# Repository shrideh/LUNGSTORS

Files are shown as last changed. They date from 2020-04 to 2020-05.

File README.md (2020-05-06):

**Full project presentation available at: https://protors.co/lungstors/**

# LUNGSTORS
**Blower based Open Source Medical Ventilator**

<p align="center">
  
  
</p>

## License
Copyright (C) 2020 PROTORS  <info@protors.co>

Licensed under CERN-OHL-P version 2

You may redistribute and modify this documentation and make products
using it under the terms of the [CERN-OHL-P v2](https://ohwr.org/project/cernohl/wikis/Documents/CERN-OHL-version-2).
This documentation is distributed WITHOUT ANY EXPRESS OR IMPLIED
WARRANTY, INCLUDING OF MERCHANTABILITY, SATISFACTORY QUALITY
AND FITNESS FOR A PARTICULAR PURPOSE. Please see the CERN-OHL-P v2
for applicable conditions.

For more information view [LICENSE.txt](./LICENSE.txt) file.

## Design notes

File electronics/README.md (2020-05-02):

**Full project presentation available at: https://protors.co/lungstors/**
# PROCESS BOARD
The *KiCad* projects of the printed circuit boards for process control are available in subfolders.

## PROCESS BOARD SMD
In folder `PROCESS_BOARD_SMD` a surface-mount device (SMD) version is available.
<p align="center">
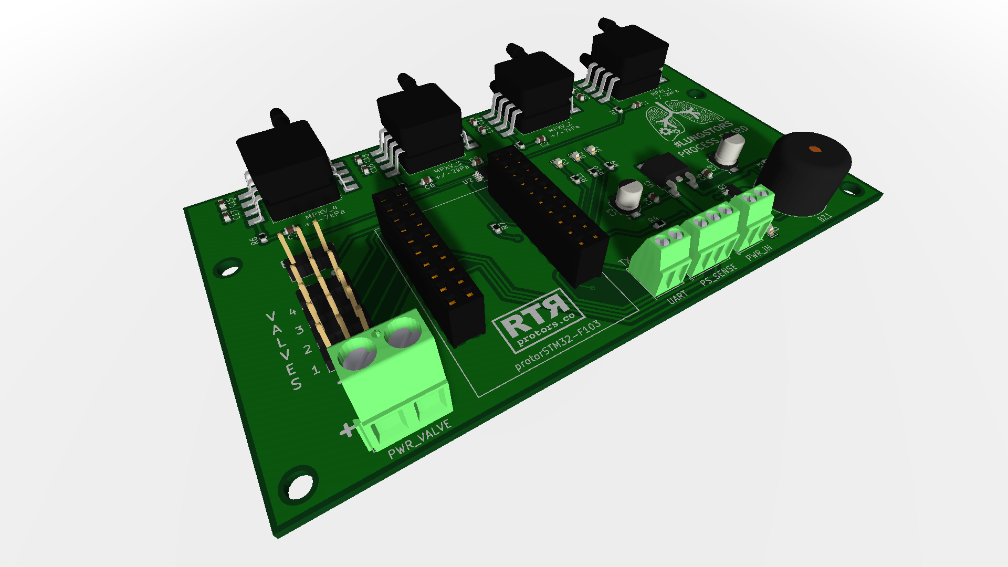
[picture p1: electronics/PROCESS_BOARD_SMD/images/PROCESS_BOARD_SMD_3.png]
  
</p>

## PROCESS BOARD TH
In folder `PROCESS_BOARD_TH` a through-hole (TH) version is available.

<p align="center">
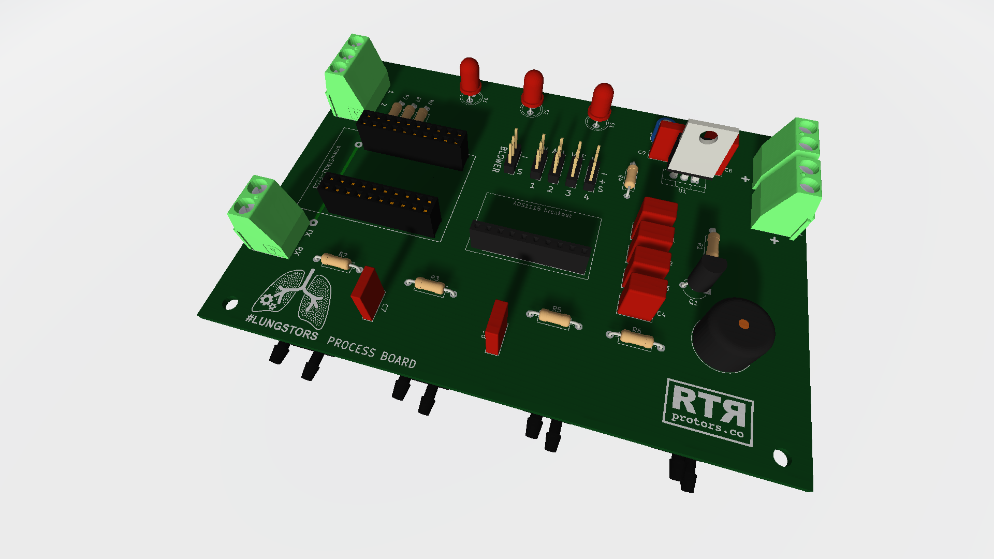
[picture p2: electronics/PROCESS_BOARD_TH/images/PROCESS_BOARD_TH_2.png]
  
</p>

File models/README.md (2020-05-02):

**Full project presentation available at: https://protors.co/lungstors/**
# 3D Models

All of technical documentation given here is made using FreeCAD. Using the FreeCAD native file format, anyone can see how we designed all the models and can easily edit and adapt the design to personal needs. FreeCAD is an open-source parametric 3D modeler made primarily to design real-life objects of any size.

## BLOWER
In folder `compressor_assembly` 3D models of our blower are available.
<p align="center">
  
</p>

## SERVO VALVE
In folder `servo_valve_assembly` 3D models of our servo valve are available.
<p align="center">
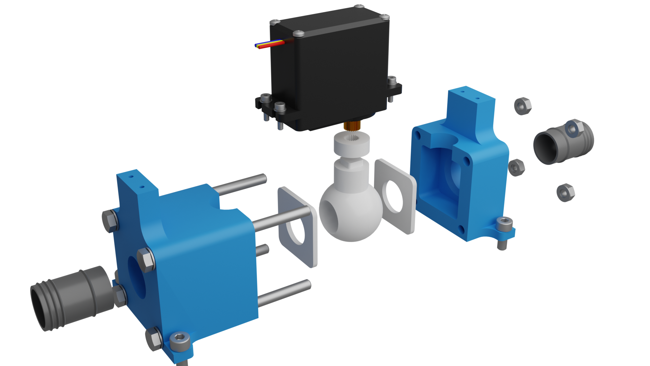
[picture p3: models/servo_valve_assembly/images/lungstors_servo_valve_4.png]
  
</p>

## FLOW METER
In folder `flowmeter_assembly` 3D models of our flow meter are available.
<p align="center">
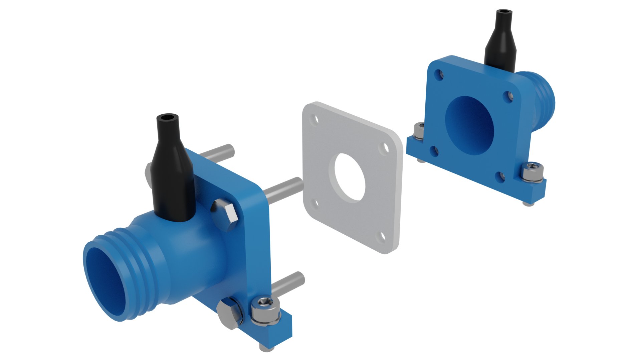
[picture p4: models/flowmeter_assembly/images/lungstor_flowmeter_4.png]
  
</p>

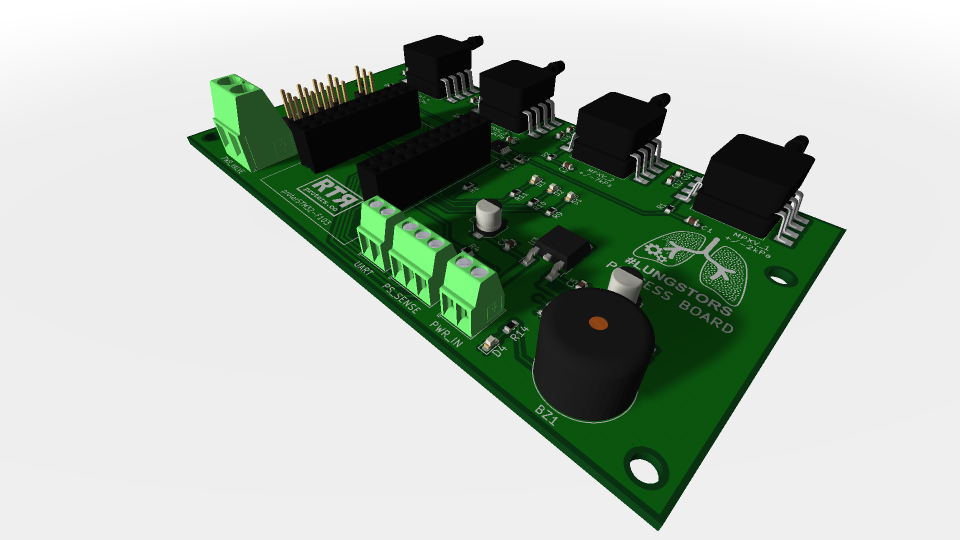
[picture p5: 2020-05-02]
electronics/PROCESS_BOARD_SMD/images/PROCESS_BOARD_SMD_4.png

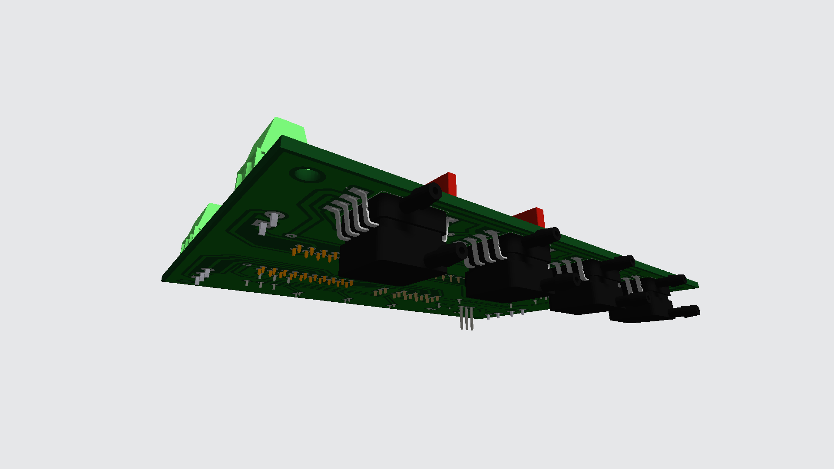
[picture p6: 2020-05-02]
electronics/PROCESS_BOARD_TH/images/PROCESS_BOARD_TH_4.png

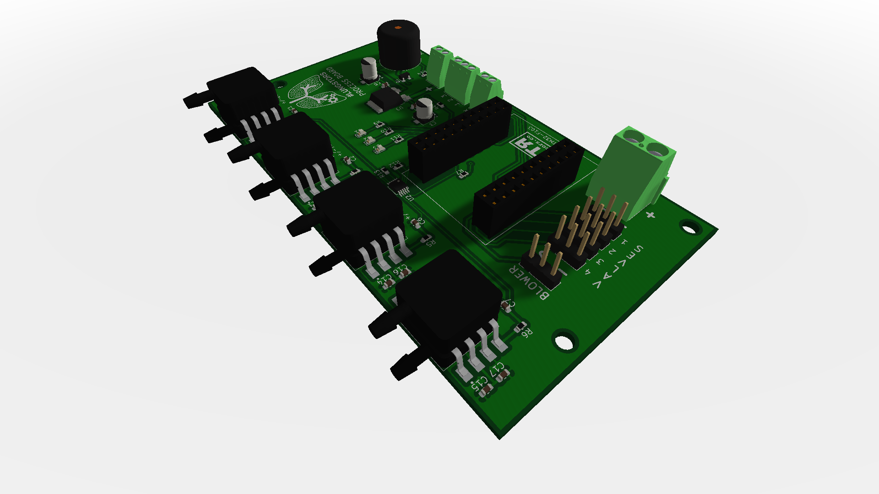
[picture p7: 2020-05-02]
electronics/PROCESS_BOARD_SMD/images/PROCESS_BOARD_SMD_1.png

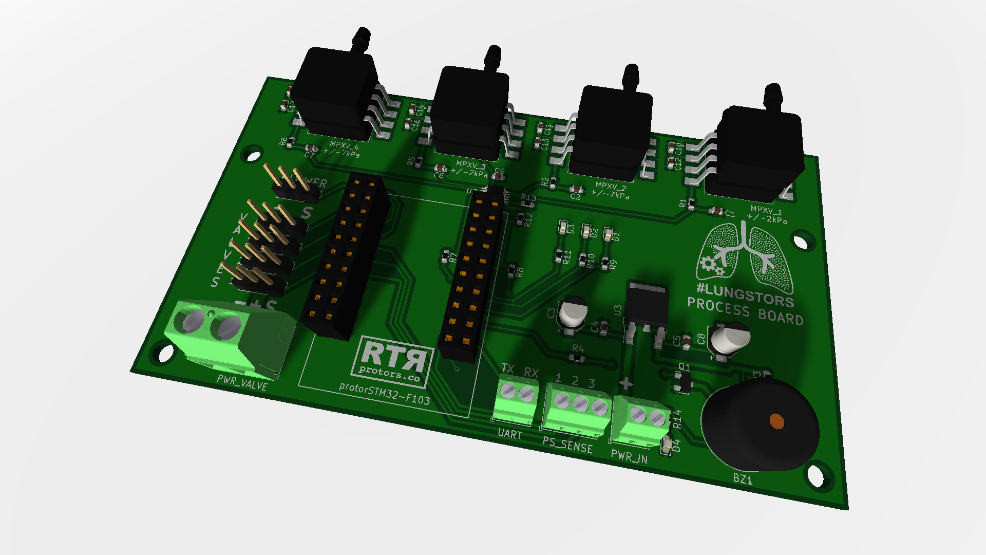
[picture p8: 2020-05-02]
electronics/PROCESS_BOARD_SMD/images/PROCESS_BOARD_SMD_2.png

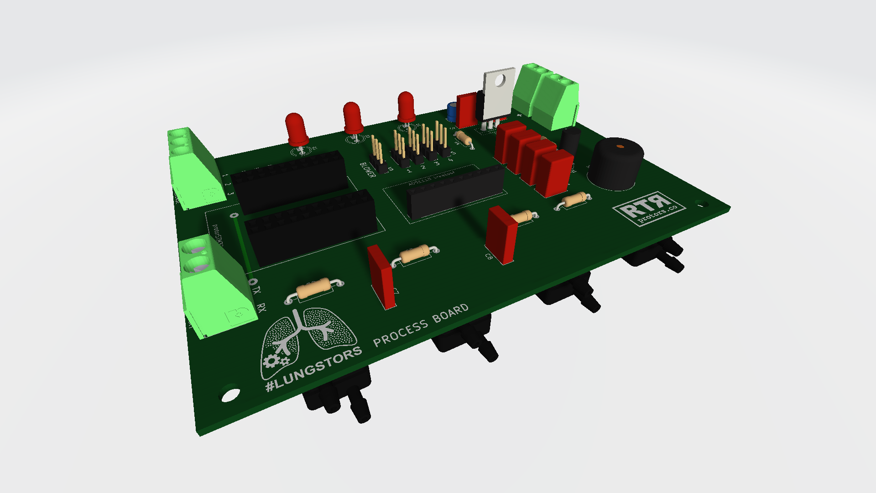
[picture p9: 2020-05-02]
electronics/PROCESS_BOARD_TH/images/PROCESS_BOARD_TH_1.png

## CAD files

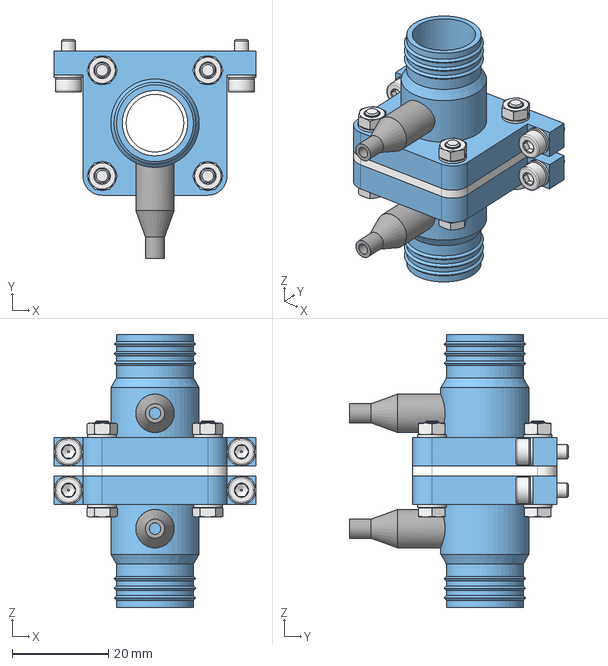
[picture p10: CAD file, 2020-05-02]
models/flowmeter_assembly/flowmeter_assembly.step
42.0 x 45.7 x 56.8 mm

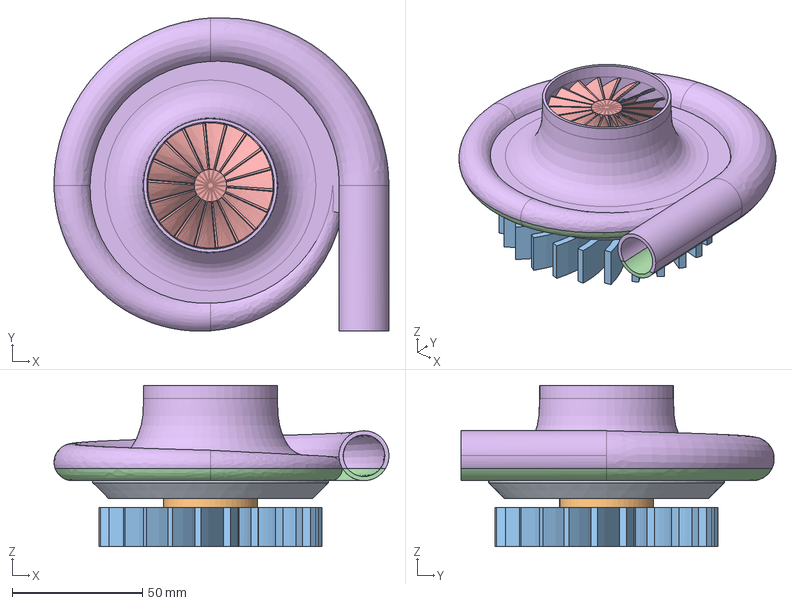
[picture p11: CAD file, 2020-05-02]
models/compressor_assembly/compressor_assembly.FCStd
128.7 x 120.4 x 61.9 mm
base_001
motor_base_001
radiator_001
volute_bottom_001
impeler_001
volute_001
bldc_motor_001

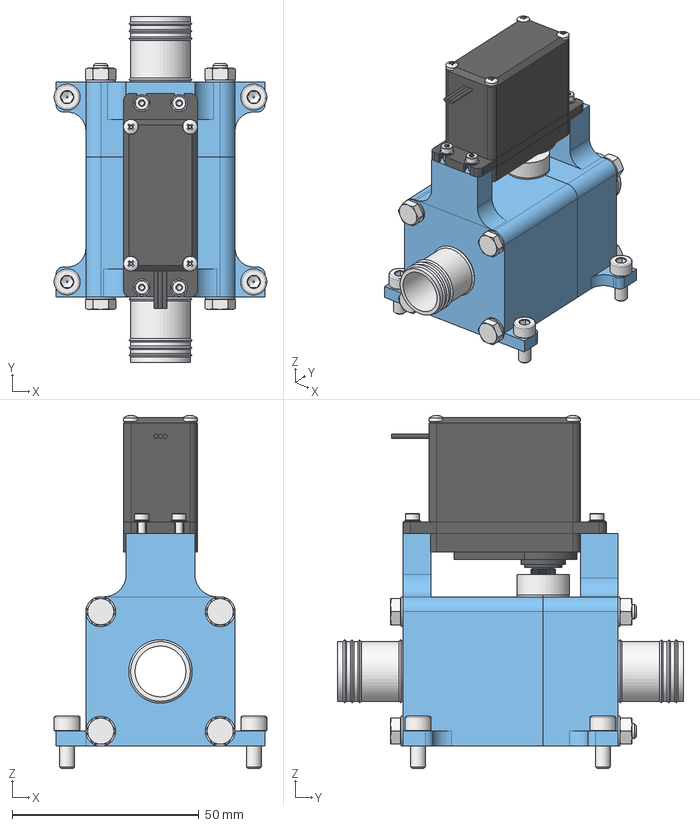
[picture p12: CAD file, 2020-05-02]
models/servo_valve_assembly/servo_valve_assembly.FCStd
57.0 x 92.8 x 94.6 mm
ball_001
ball_002
coupling_001
housing_left_001
housing_right_001
servo_001
gasket_001
gasket_002
hose_connector_001
hose_connector_002
M4x10-Screw
M4x10-Screw003
M4x10-Screw001
M4x10-Screw002
M2x5-Screw
M2x5-Screw004
M2x5-Screw005
M2x5-Screw006
M4-Washer
M4-Washer001
M4-Washer002
M4-Washer003
M4-Washer004
M4-Washer005
M4-Washer006
M4-Washer007
M4-Nut
M4-Nut001
M4-Nut002
M4-Nut003
M4x63-Screw
M4x63-Screw001
M4x63-Screw003
M4x63-Screw002
M2-Washer
M2-Washer001
M2-Washer002
M2-Washer003
M2x8-Screw
M2x8-Screw001
M2x8-Screw002
M2x8-Screw003

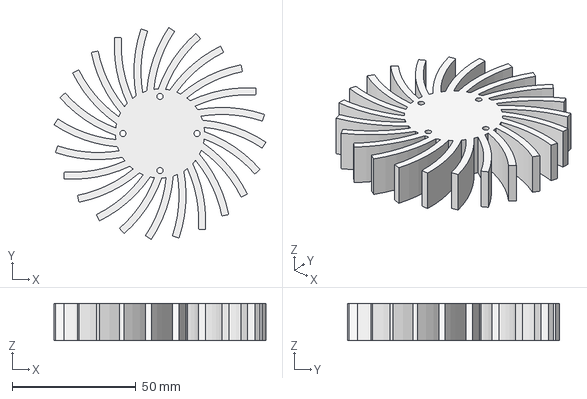
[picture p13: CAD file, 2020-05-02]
models/compressor_assembly/radiator.step
85.7 x 85.7 x 15.0 mm

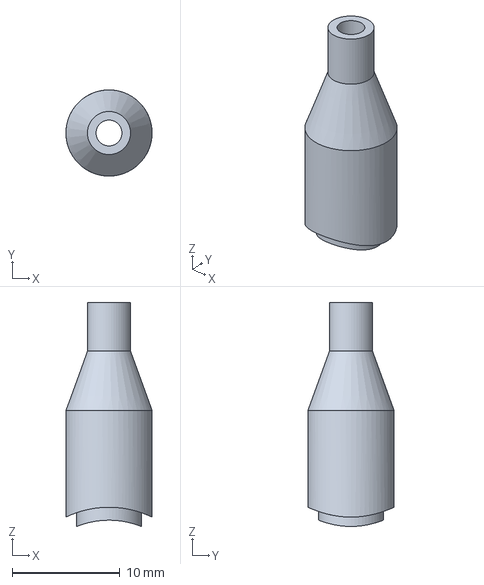
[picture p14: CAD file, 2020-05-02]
models/flowmeter_assembly/pressure_connector.step
8.00 x 8.00 x 20.8 mm

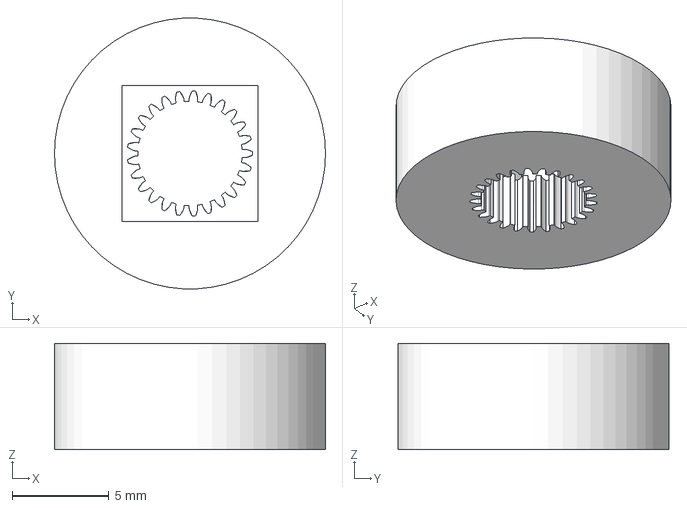
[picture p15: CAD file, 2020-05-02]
models/servo_valve_assembly/coupling.step
14.0 x 14.0 x 5.50 mm

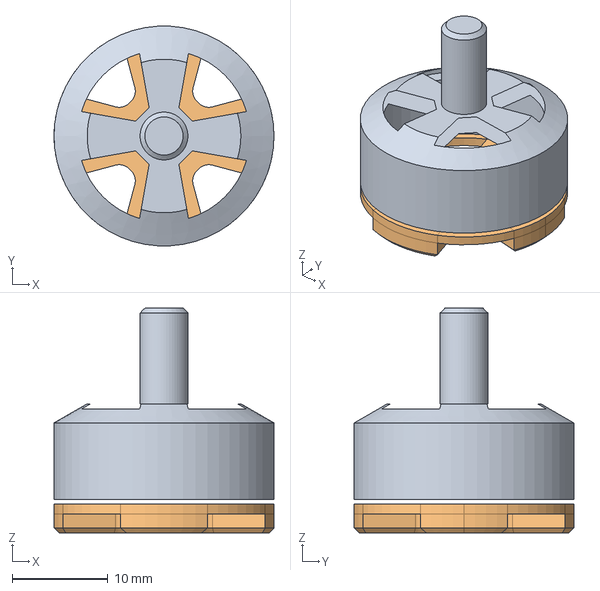
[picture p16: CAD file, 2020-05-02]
models/compressor_assembly/bldc_motor.step
23.0 x 23.0 x 23.5 mm

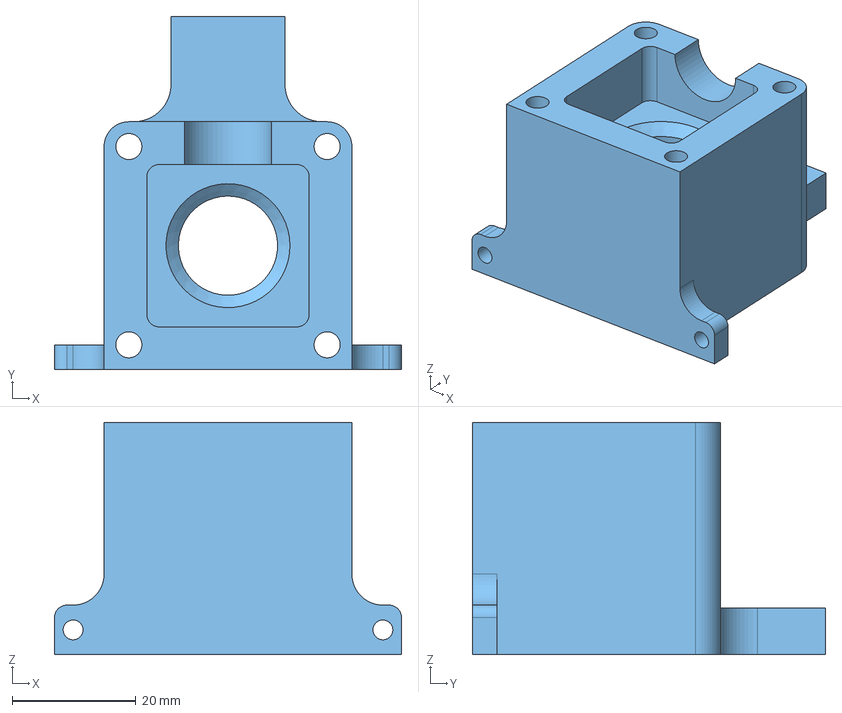
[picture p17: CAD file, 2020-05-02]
models/servo_valve_assembly/housing_right.step
56.0 x 57.0 x 37.5 mm

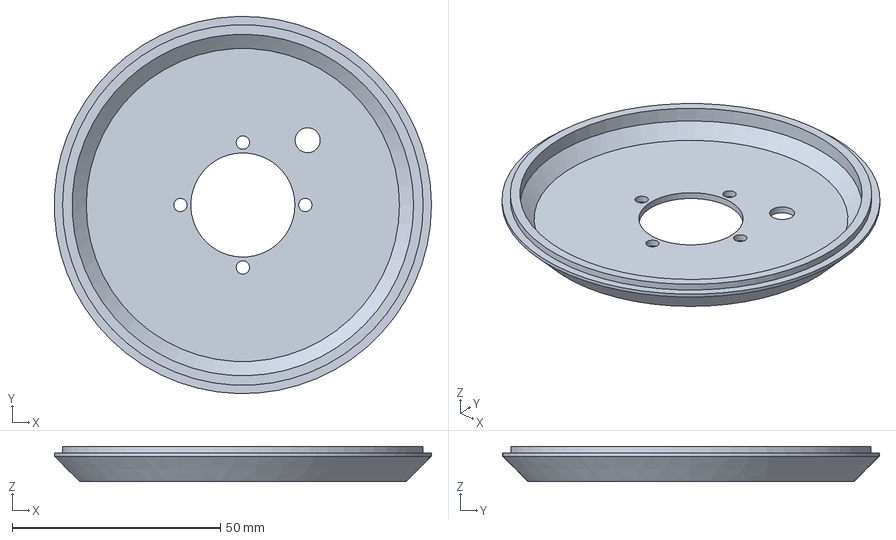
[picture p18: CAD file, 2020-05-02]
models/compressor_assembly/base.step
90.5 x 90.6 x 8.50 mm

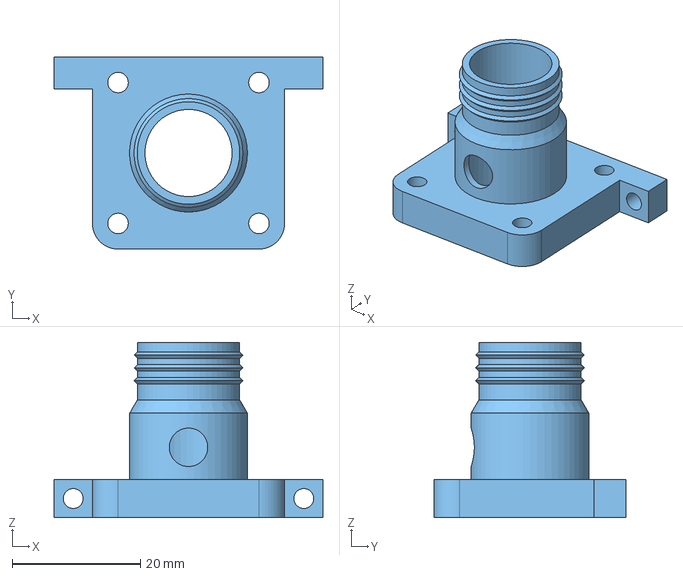
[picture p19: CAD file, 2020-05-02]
models/flowmeter_assembly/housing.step
42.0 x 30.0 x 27.4 mm

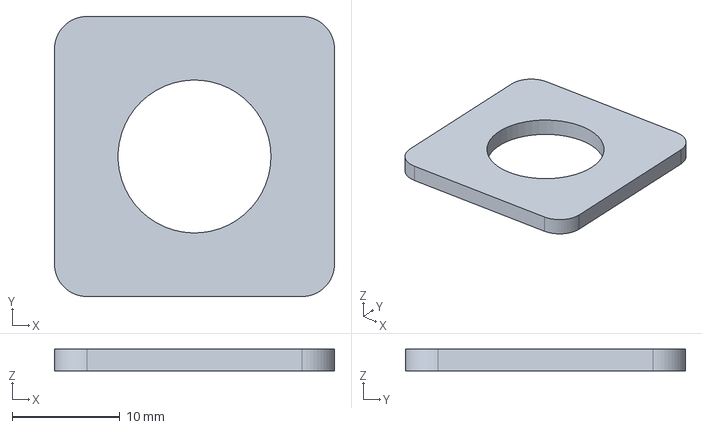
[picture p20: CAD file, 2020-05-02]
models/servo_valve_assembly/gasket.step
26.0 x 26.0 x 2.00 mm

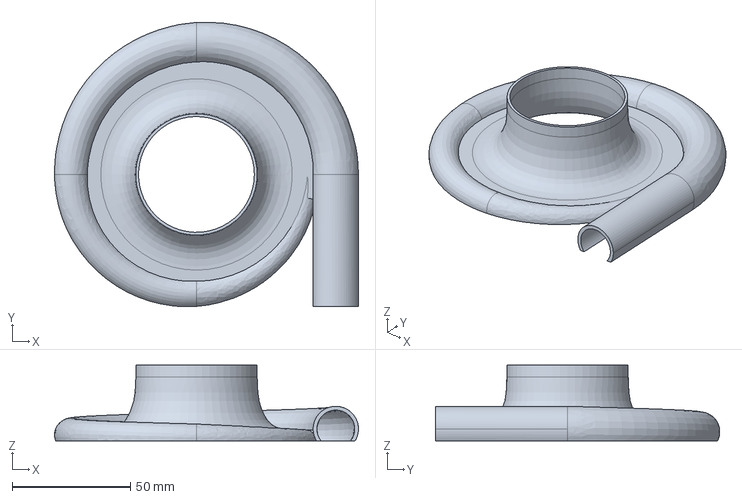
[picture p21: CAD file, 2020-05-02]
models/compressor_assembly/volute_top.step
128.7 x 120.4 x 32.0 mm

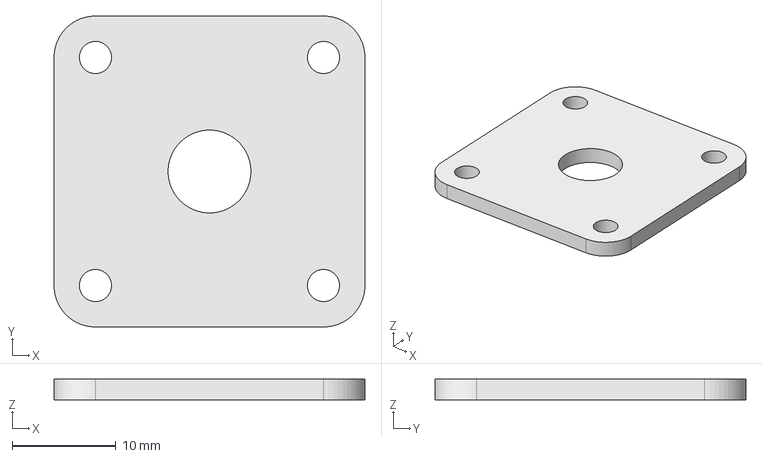
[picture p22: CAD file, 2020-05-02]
models/flowmeter_assembly/orifice.step
30.0 x 30.0 x 2.00 mm

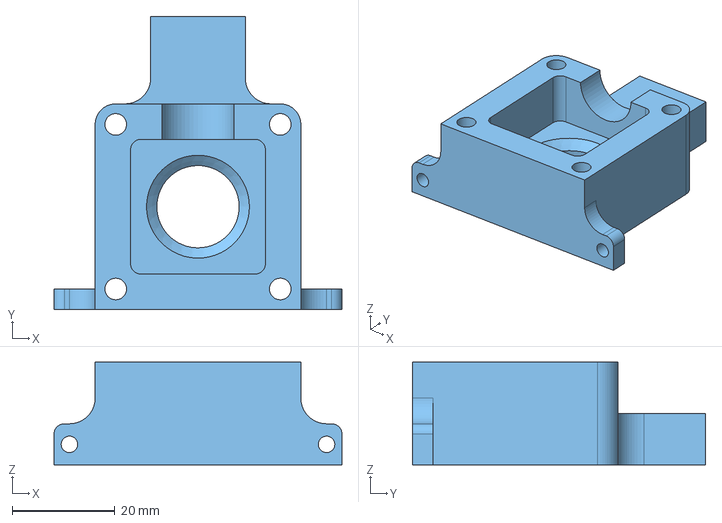
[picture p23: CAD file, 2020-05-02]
models/servo_valve_assembly/housing_left.step
56.0 x 57.0 x 20.0 mm

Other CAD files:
models/compressor_assembly/impeler.stl
models/servo_valve_assembly/hose_connector.step
models/compressor_assembly/volute_bottom.step
models/servo_valve_assembly/ball.step
models/compressor_assembly/base.FCStd
models/compressor_assembly/base.stl
models/compressor_assembly/bldc_motor.FCStd
models/compressor_assembly/bldc_motor.stl
models/compressor_assembly/motor_base.FCStd
models/compressor_assembly/motor_base.step
models/compressor_assembly/motor_base.stl
models/compressor_assembly/radiator.FCStd
models/compressor_assembly/radiator.stl
models/compressor_assembly/volute_bottom.FCStd
models/compressor_assembly/volute_bottom.stl
models/compressor_assembly/volute_top.FCStd
models/compressor_assembly/volute_top.stl
models/flowmeter_assembly/flowmeter_assembly.FCStd
models/flowmeter_assembly/flowmeter_assembly.stl
models/flowmeter_assembly/housing.FCStd
models/flowmeter_assembly/housing.stl
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

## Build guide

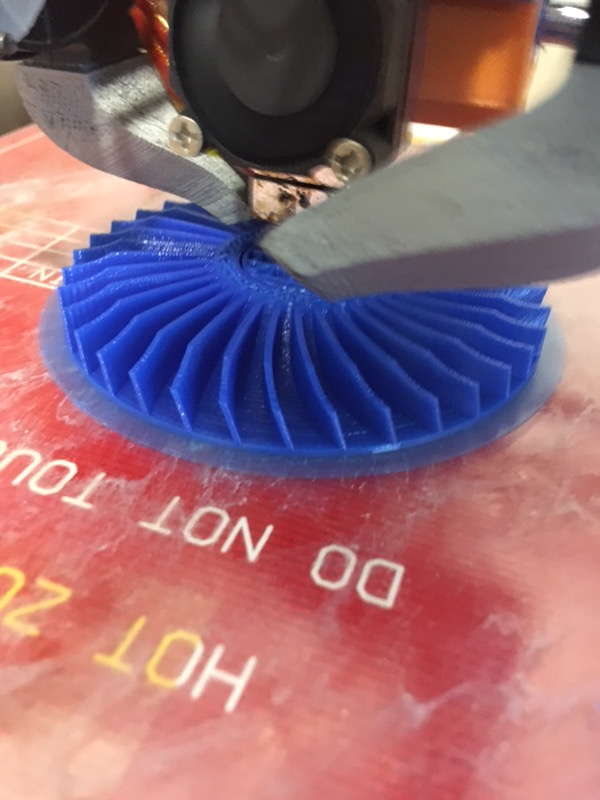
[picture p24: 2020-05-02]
models/compressor_assembly/images/lungstors_blower_2.JPG

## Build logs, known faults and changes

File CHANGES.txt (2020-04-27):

--------------------
LUNGSTORS
Blower based Open Source Mechanical Ventilator
--------------------

Release 1.0.0, 27.04.2020.

- Initial release

--------------------

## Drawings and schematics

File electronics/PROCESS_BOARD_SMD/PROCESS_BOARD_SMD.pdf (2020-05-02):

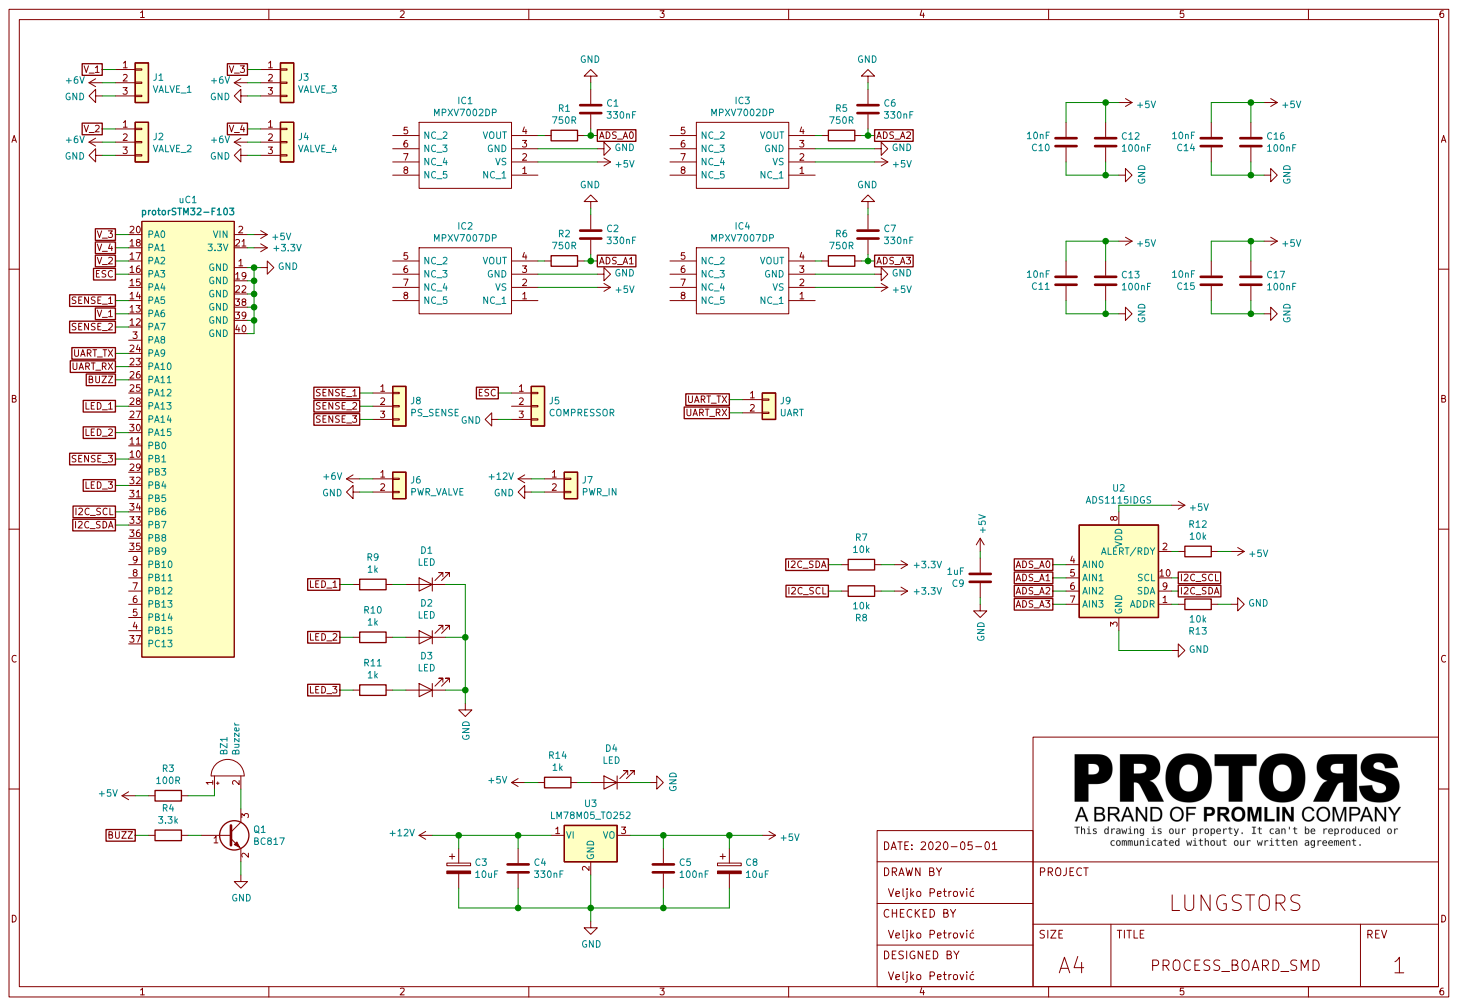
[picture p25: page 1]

2 BZ1 Buzzer NC_1 1 VS 2 GND 3 VOUT 4 NC_2 5 NC_3 6 NC_4 7 NC_5 8

DESIGNED BY CHECKED BY DRAWN BY
LUNGSTORS Veljko Petrovi

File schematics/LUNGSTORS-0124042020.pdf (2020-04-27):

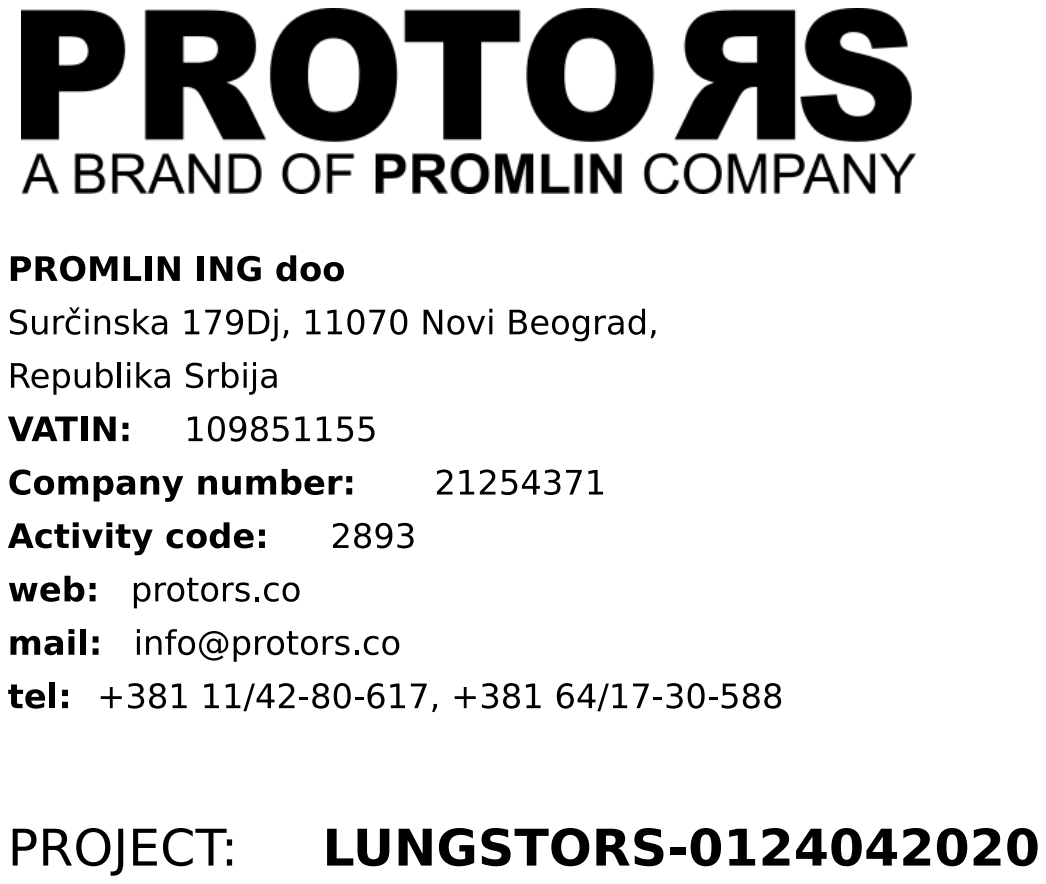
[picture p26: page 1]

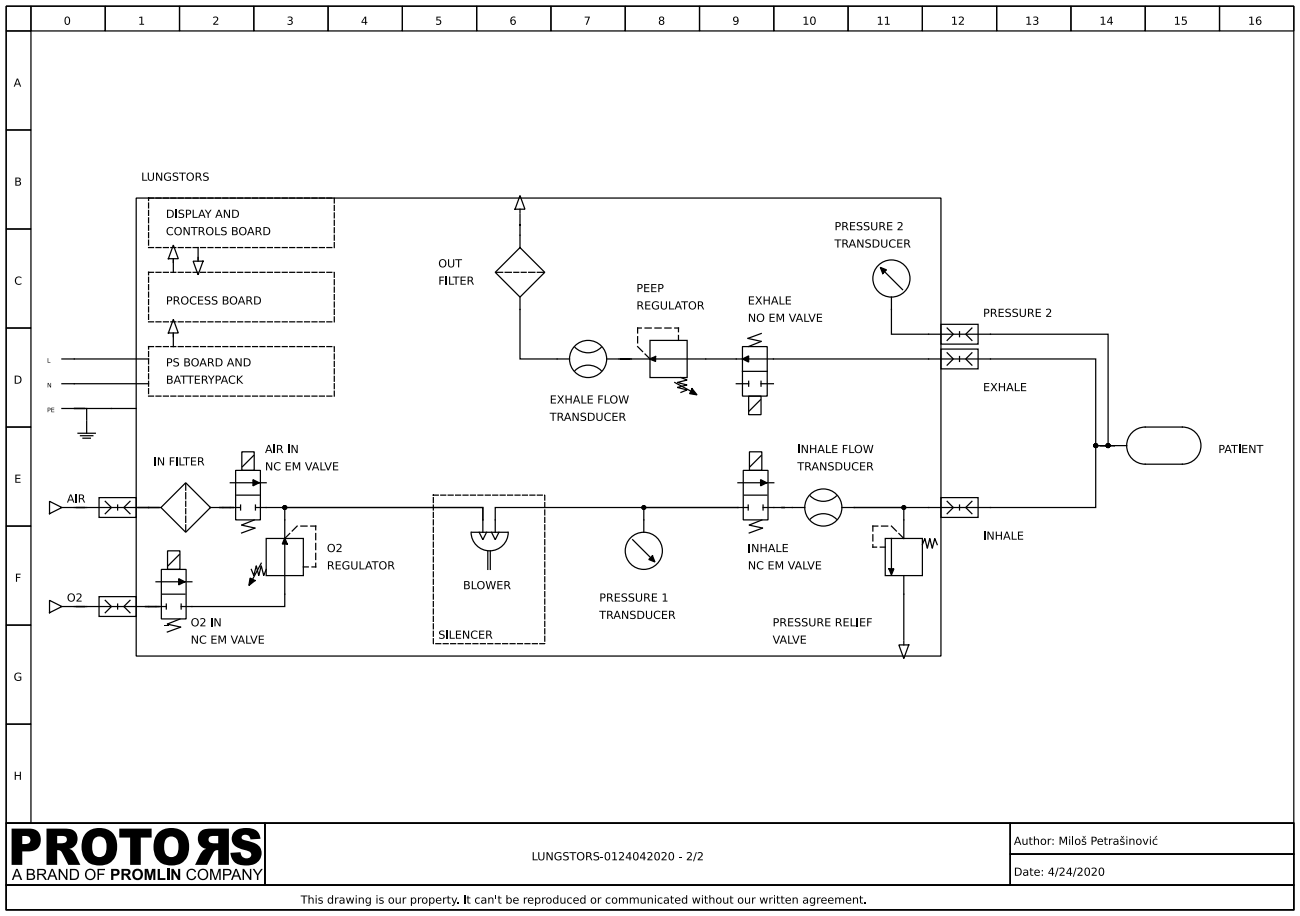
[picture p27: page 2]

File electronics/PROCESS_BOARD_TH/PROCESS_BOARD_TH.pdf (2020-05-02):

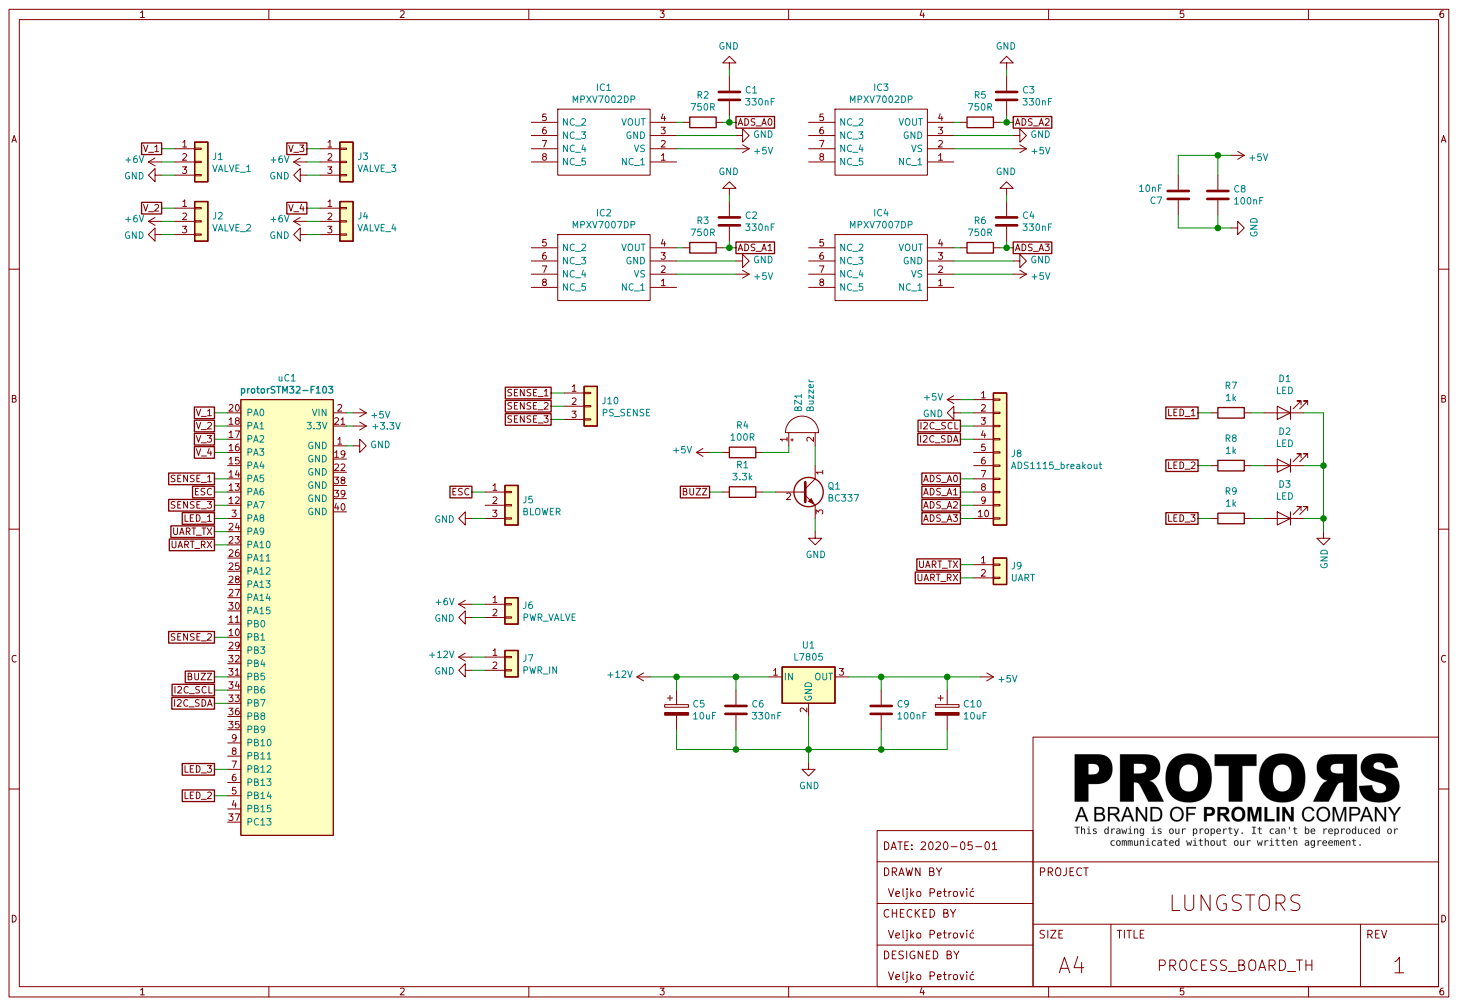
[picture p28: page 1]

DESIGNED BY CHECKED BY DRAWN BY | | LUNGSTORS Veljko Petrovi

PROCESS_BOARD_TH | 1 | D A4

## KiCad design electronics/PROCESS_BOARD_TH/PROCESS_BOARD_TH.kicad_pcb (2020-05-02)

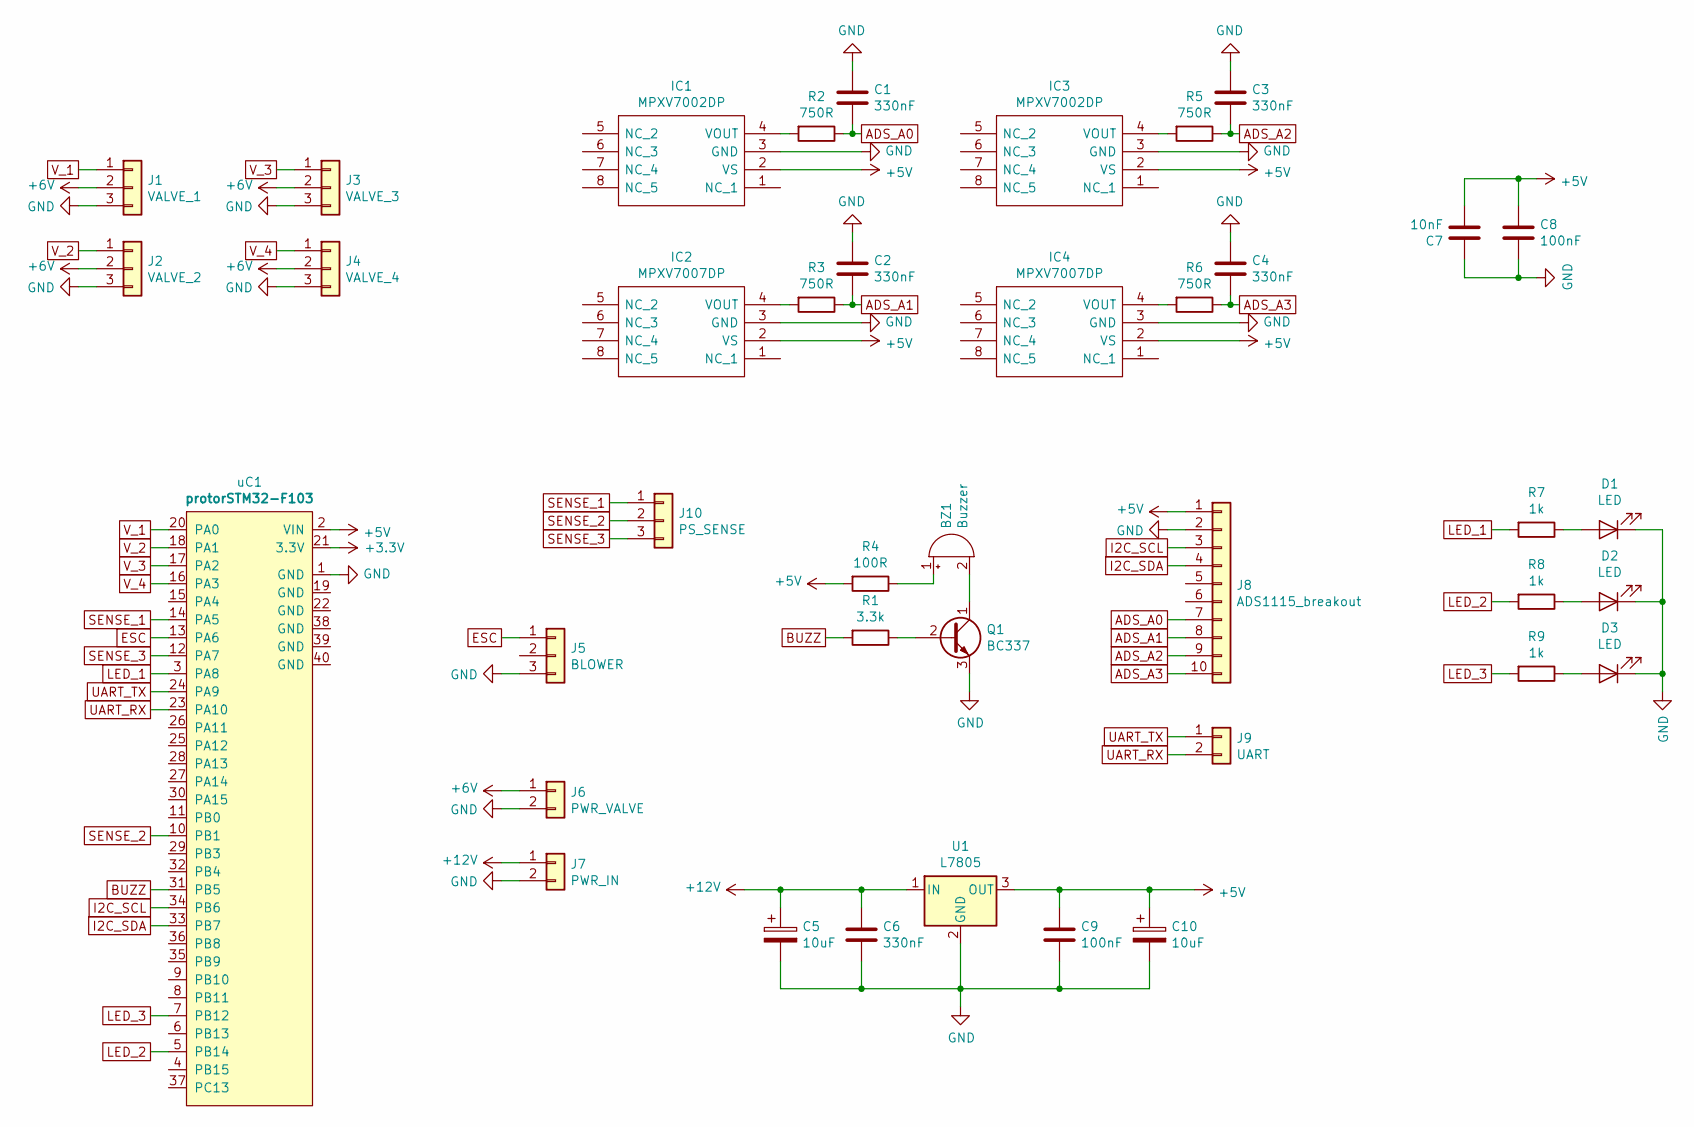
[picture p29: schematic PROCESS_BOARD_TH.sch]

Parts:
BZ1: Buzzer; Buzzer_12x9.5RM7.6
C1, C2, C3, C4, C6: 330nF; C_Rect_L7.0mm_W4.5mm_P5.00mm
C5, C10: 10uF; CP_Radial_D5.0mm_P2.50mm
C7: 10nF; C_Rect_L7.0mm_W2.0mm_P5.00mm
C8, C9: 100nF; C_Rect_L7.0mm_W2.5mm_P5.00mm
D1, D2, D3: LED; LED_D5.0mm
IC1, IC3: MPXV7002DP; MPXV7002DPT1
IC2, IC4: MPXV7007DP; MPXV7002DPT1
J1: VALVE_1; PinHeader_1x03_P2.54mm_Vertical
J2: VALVE_2; PinHeader_1x03_P2.54mm_Vertical
J3: VALVE_3; PinHeader_1x03_P2.54mm_Vertical
J4: VALVE_4; PinHeader_1x03_P2.54mm_Vertical
J5: BLOWER; PinHeader_1x03_P2.54mm_Vertical
J6: PWR_VALVE; TerminalBlock_bornier-2_P5.08mm
J7: PWR_IN; TerminalBlock_bornier-2_P5.08mm
J8: ADS1115_breakout; PinSocket_1x10_P2.54mm_Vertical
J9: UART; TerminalBlock_bornier-2_P5.08mm
J10: PS_SENSE; TerminalBlock_bornier-3_P5.08mm
Q1: BC337; TO-92L_Inline_Wide
R1: 3.3k; R_Axial_DIN0207_L6.3mm_D2.5mm_P10.16mm_Horizontal
R2, R3, R5, R6: 750R; R_Axial_DIN0207_L6.3mm_D2.5mm_P10.16mm_Horizontal
R4: 100R; R_Axial_DIN0207_L6.3mm_D2.5mm_P10.16mm_Horizontal
R7, R8, R9: 1k; R_Axial_DIN0207_L6.3mm_D2.5mm_P10.16mm_Horizontal
U1: L7805; TO-220-3_Vertical
uC1: protorSTM32-F103; protorSTM32-F103v1.1

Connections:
+5V: C7.2, C8.1, C9.1, C10.1, IC1.2 (VS), IC2.2 (VS), IC3.2 (VS), IC4.2 (VS), J8.1, R4.2, U1.3 (OUT), uC1.2 (VIN)
+6V: J1.2, J2.2, J3.2, J4.2, J6.1
+12V: C5.1, C6.1, J7.1, U1.1 (IN)
ADS_A0: C1.2, J8.7, R2.1
ADS_A1: C2.2, J8.8, R3.1
ADS_A2: C3.2, J8.9, R5.1
ADS_A3: C4.2, J8.10, R6.1
BUZZ: R1.2, uC1.31 (PB5)
ESC: J5.1, uC1.13 (PA6)
GND: C1.1, C2.1, C3.1, C4.1, C5.2, C6.2, C7.1, C8.2, C9.2, C10.2, D1.1 (K), D2.1 (K), D3.1 (K), IC1.3 (GND), IC2.3 (GND), IC3.3 (GND), IC4.3 (GND), J1.3, J2.3, J3.3, J4.3, J5.3, J6.2, J7.2, J8.2, Q1.3 (E), U1.2 (GND), uC1.1 (GND)
I2C_SCL: J8.3, uC1.34 (PB6)
I2C_SDA: J8.4, uC1.33 (PB7)
LED_1: R7.2, uC1.3 (PA8)
LED_2: R8.2, uC1.5 (PB14)
LED_3: R9.2, uC1.7 (PB12)
unnamed: BZ1.1 (-), R4.1
unnamed: BZ1.2 (+), Q1.1 (C)
unnamed: D1.2 (A), R7.1
unnamed: D2.2 (A), R8.1
unnamed: D3.2 (A), R9.1
unnamed: IC1.4 (VOUT), R2.2
unnamed: IC2.4 (VOUT), R3.2
unnamed: IC3.4 (VOUT), R5.2
unnamed: IC4.4 (VOUT), R6.2
unnamed: Q1.2 (B), R1.1
SENSE_1: J10.1, uC1.14 (PA5)
SENSE_2: J10.2, uC1.10 (PB1)
SENSE_3: J10.3, uC1.12 (PA7)
UART_RX: J9.2, uC1.23 (PA10)
UART_TX: J9.1, uC1.24 (PA9)
V_1: J1.1, uC1.20 (PA0)
V_2: J2.1, uC1.18 (PA1)
V_3: J3.1, uC1.17 (PA2)
V_4: J4.1, uC1.16 (PA3)

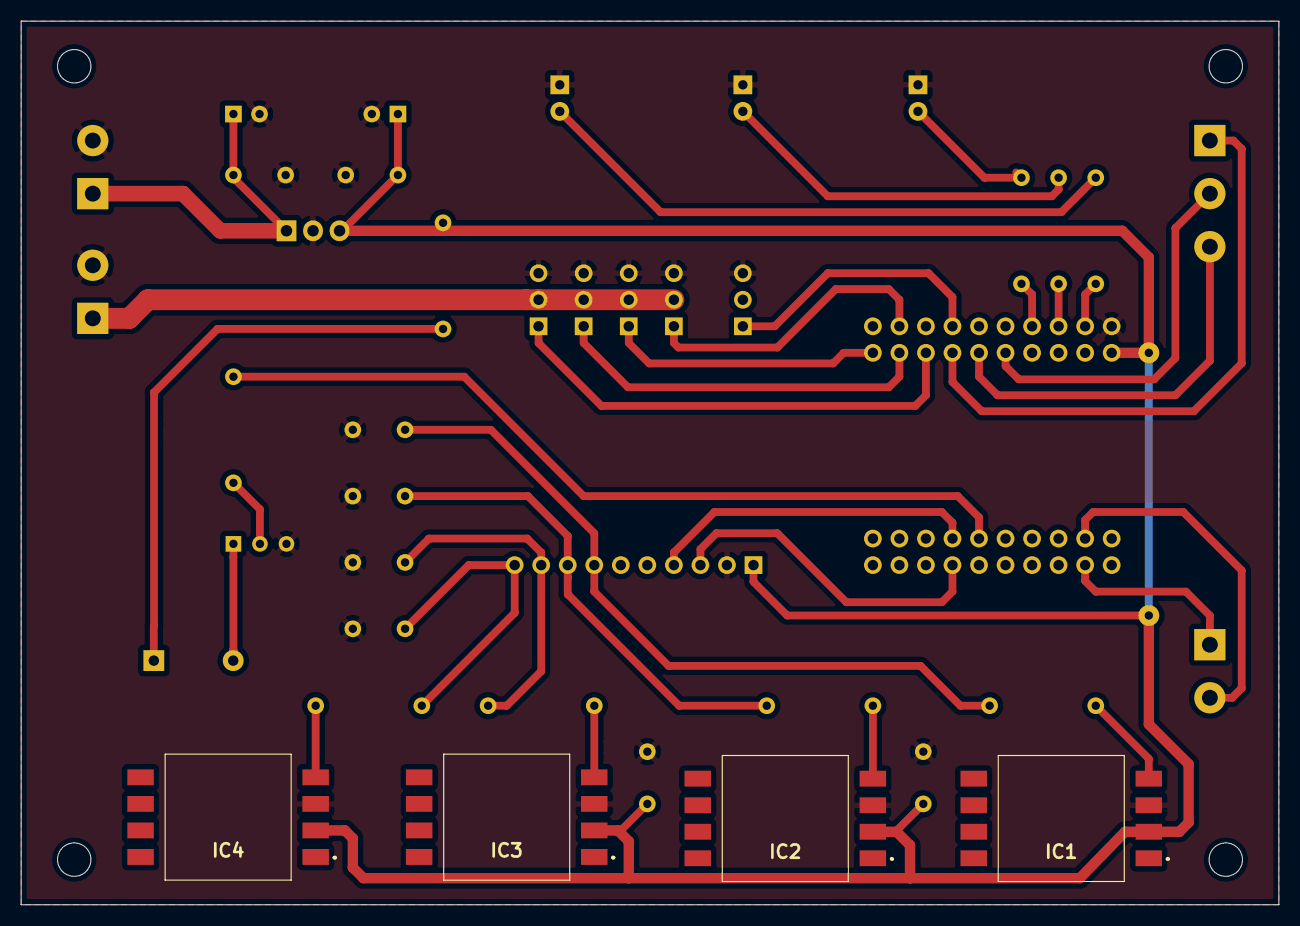
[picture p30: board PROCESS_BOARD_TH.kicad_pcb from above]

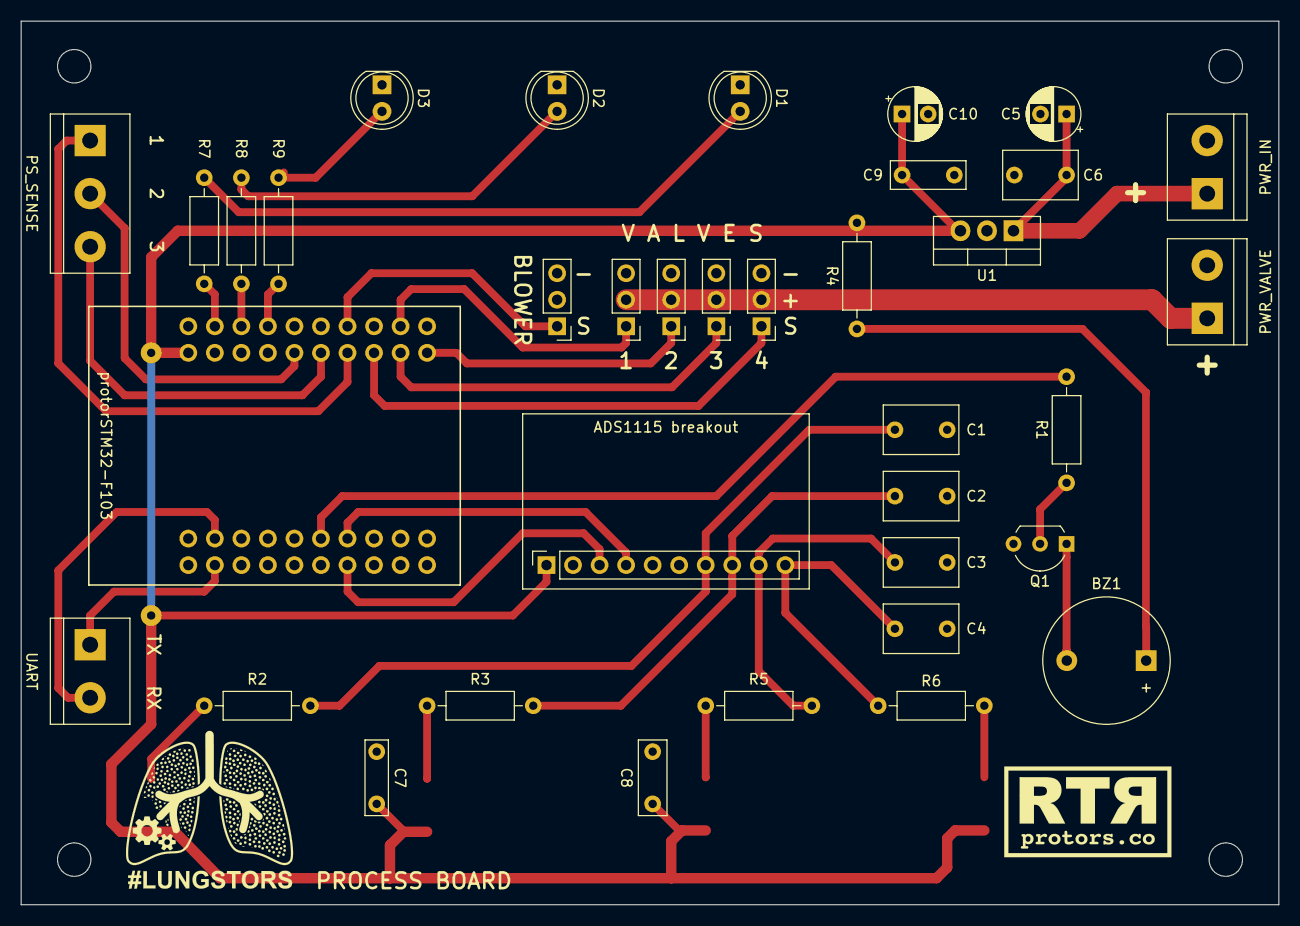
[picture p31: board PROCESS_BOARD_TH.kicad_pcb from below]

Board: 2 copper layers, 120.4 x 84.6 mm, 40 parts (36 on the bottom side), 34 nets.

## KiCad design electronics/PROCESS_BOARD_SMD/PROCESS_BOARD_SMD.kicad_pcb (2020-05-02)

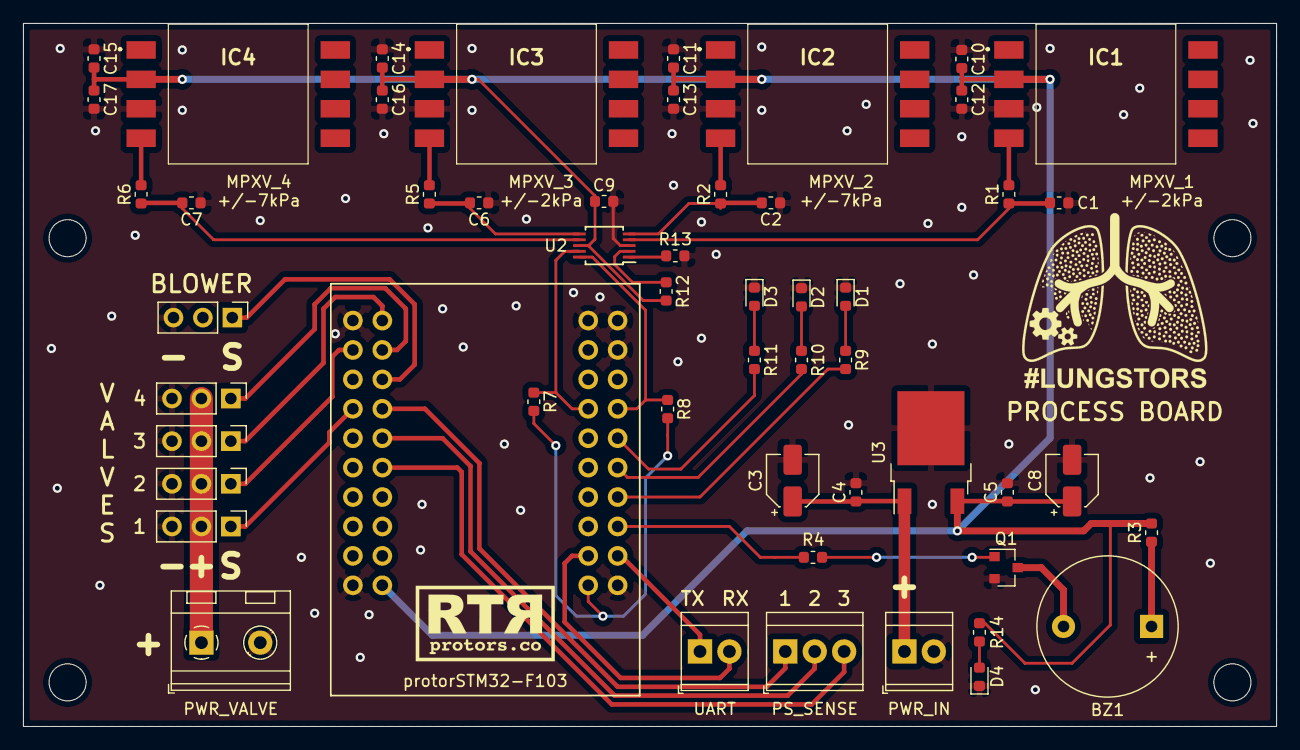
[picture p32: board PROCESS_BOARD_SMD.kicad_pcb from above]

Board: 2 copper layers, 108.2 x 60.7 mm, 53 parts (0 on the bottom side), 38 nets.

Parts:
BZ1: Buzzer; Buzzer_12x9.5RM7.6
C1, C2, C4, C6, C7: 330nF; C_0603_1608Metric
C3: 10uF; CP_Elec_4x4.5
C5, C12, C13, C16, C17: 100nF; C_0603_1608Metric
C8: 10uF; CP_Elec_4x5.4
C9: 1uF; C_0603_1608Metric
C10, C11, C14, C15: 10nF; C_0603_1608Metric
D1, D2, D3, D4: LED; LED_0603_1608Metric
IC1, IC3: MPXV7002DP; MPXV7002DPT1
IC2, IC4: MPXV7007DP; MPXV7002DPT1
J1: VALVE_1; PinHeader_1x03_P2.54mm_Vertical
J2: VALVE_2; PinHeader_1x03_P2.54mm_Vertical
J3: VALVE_3; PinHeader_1x03_P2.54mm_Vertical
J4: VALVE_4; PinHeader_1x03_P2.54mm_Vertical
J5: COMPRESSOR; PinHeader_1x03_P2.54mm_Vertical
J6: PWR_VALVE; TerminalBlock_RND_205-00232_1x02_P5.08mm_Horizontal
J7: PWR_IN; TerminalBlock_TE_282834-2_1x02_P2.54mm_Horizontal
J8: PS_SENSE; TerminalBlock_TE_282834-3_1x03_P2.54mm_Horizontal
J9: UART; TerminalBlock_TE_282834-2_1x02_P2.54mm_Horizontal
Q1: BC817; SOT-23
R1, R2, R5, R6: 750R; R_0603_1608Metric
R3: 100R; R_0603_1608Metric
R4: 3.3k; R_0603_1608Metric
R7, R8, R12, R13: 10k; R_0603_1608Metric
R9, R10, R11, R14: 1k; R_0603_1608Metric
U2: ADS1115IDGS; TSSOP-10_3x3mm_P0.5mm
U3: LM78M05_TO252; TO-252-2
uC1: protorSTM32-F103; protorSTM32-F103v1.1

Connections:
+3V3: R7.2, R8.2, uC1.21
+5V: C5.1, C8.1, C9.2, C10.2, C11.2, C12.1, C13.1, C14.2, C15.2, C16.1, C17.1, IC1.2, IC2.2, IC3.2, IC4.2, R3.2, R12.2, R14.2, U2.8, U3.3, uC1.2
+6V: J1.2, J2.2, J3.2, J4.2, J6.1
+12V: C3.1, C4.1, J7.1, U3.1
ADS_A0: C1.2, R1.1, U2.4
ADS_A1: C2.2, R2.1, U2.5
ADS_A2: C6.2, R5.1, U2.6
ADS_A3: C7.2, R6.1, U2.7
BUZZ: R4.2, uC1.26
ESC: J5.1, uC1.16
GND: C1.1, C2.1, C3.2, C4.2, C5.2, C6.1, C7.1, C8.2, C9.1, C10.1, C11.1, C12.2, C13.2, C14.1, C15.1, C16.2, C17.2, D1.1, D2.1, D3.1, D4.1, IC1.3, IC2.3, IC3.3, IC4.3, J1.3, J2.3, J3.3, J4.3, J5.3, J6.2, J7.2, Q1.2, R13.2, U2.3, U3.2, uC1.1, uC1.19, uC1.22, uC1.38, uC1.39, uC1.40
I2C_SCL: R8.1, U2.10, uC1.34
I2C_SDA: R7.1, U2.9, uC1.33
LED_1: R9.2, uC1.28
LED_2: R10.2, uC1.30
LED_3: R11.2, uC1.32
unnamed: BZ1.1, R3.1
unnamed: BZ1.2, Q1.3
unnamed: D1.2, R9.1
unnamed: D2.2, R10.1
unnamed: D3.2, R11.1
unnamed: D4.2, R14.1
unnamed: IC1.4, R1.2
unnamed: IC2.4, R2.2
unnamed: IC3.4, R5.2
unnamed: IC4.4, R6.2
unnamed: Q1.1, R4.1
unnamed: R12.1, U2.2
unnamed: R13.1, U2.1
SENSE_1: J8.1, uC1.14
SENSE_2: J8.2, uC1.12
SENSE_3: J8.3, uC1.10
UART_RX: J9.2, uC1.23
UART_TX: J9.1, uC1.24
V_1: J1.1, uC1.13
V_2: J2.1, uC1.17
V_3: J3.1, uC1.20
V_4: J4.1, uC1.18

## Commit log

2020-05-02 Add PROCESS BOARD
    [PROCESS_BOARD_SMD.kicad_pcb, PROCESS_BOARD_SMD.sch, PROCESS_BOARD_TH.kicad_pcb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]
2020-05-02 Add models
    [ball.FCStd, ball.step, ball.stl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]
